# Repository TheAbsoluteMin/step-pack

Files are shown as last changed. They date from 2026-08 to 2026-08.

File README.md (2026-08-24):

# step-pack

















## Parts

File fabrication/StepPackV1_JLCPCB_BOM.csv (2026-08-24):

Designator | Value | Footprint | LCSC Part Number
C2 | 4.7uF_100V_BUCK | Capacitor_SMD:C_1206_3216Metric | C22367839
C3,C5 | 22uF_25V | Capacitor_SMD:C_0805_2012Metric | C45783
C4,C9,C11,C12,C21 | 0.1uF_50V | Capacitor_SMD:C_0603_1608Metric | C14663
C6,C13 | 1uF_50V | Capacitor_SMD:C_0603_1608Metric | C15849
D1 | WS2812B-2020 | LED_SMD:LED_WS2812B-2020_PLCC4_2.0x2.0mm | C5349955
D4 | D_Zener_SMCJ30A | Diode_SMD:D_SMC | C408374
D5 | D_Schottky_60V | Diode_SMD:D_SOD-123F | C116099
D6,D7 | PMEG3010BEA | Diode_SMD:D_SOD-323 | C53100376
J2 | USB_C_Receptacle_USB2.0_16P | Connector_USB:USB_C_Receptacle_HRO_TYPE-C-31-M-12 | C165948
J4 | I2C_CONN | Connector_JST:JST_SH_SM04B-SRSS-TB_1x04-1MP_P1.00mm_Horizontal | C51940130
L1 | Inductor_10uH_1.2A | Inductor_SMD:L_Bourns-SRN4018 | C5291802
R3,R4 | 5.1k_USB_CC | Resistor_SMD:R_0603_1608Metric | C23186
R5,R6 | 10k | Resistor_SMD:R_0603_1608Metric | C25804
R7,R8,R9 | 22ohms | Resistor_SMD:R_0603_1608Metric | C23345
R10 | 100k_BUCK | Resistor_SMD:R_0603_1608Metric | C25803
R12 | 1k_UART | Resistor_SMD:R_0603_1608Metric | C21190
R15,R16 | 4.7k | Resistor_SMD:R_0603_1608Metric | C23162
SW2,SW3 | SW_Push | Button_Switch_SMD:SW_SPST_B3U-1000P | C49234121
U1 | ESP32-S3-MINI-1 | RF_Module:ESP32-S2-MINI-1 | C2913206
U4 | USBLC6-2SC6 | Package_TO_SOT_SMD:SOT-23-6 | C2827654
U5 | AP2112K-3.3 | Package_TO_SOT_SMD:SOT-23-5 | C51118
U6 | LMR16006YQ5 | Package_TO_SOT_SMD:SOT-23-6 | C962072

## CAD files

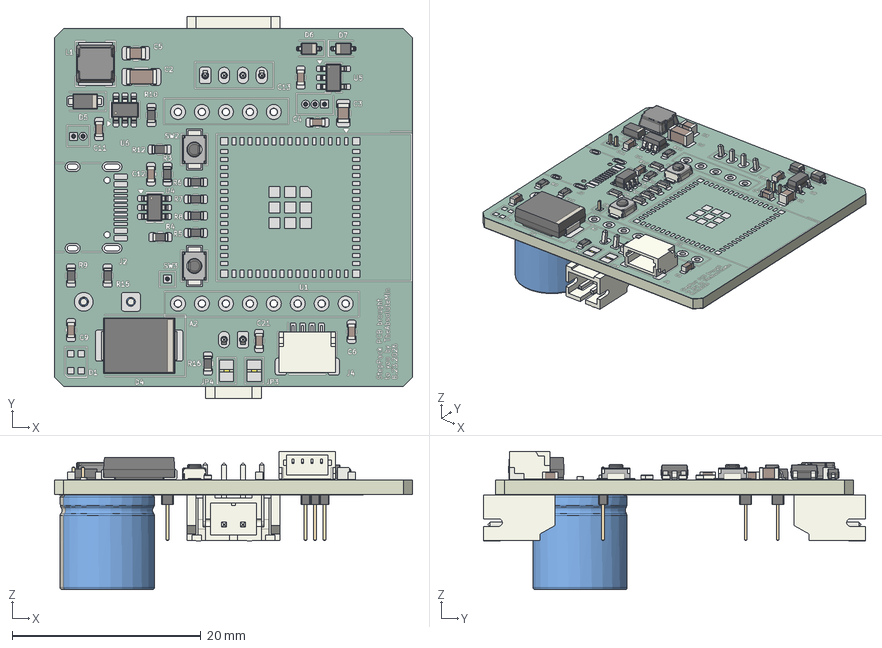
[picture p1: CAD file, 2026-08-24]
3D_Models/StepPack_PCB.step
38.0 x 40.5 x 14.6 mm
R_0603_1608Metric x 11
SOT-23-6 x 2
SW_SPST_B3U-1000P x 2
C_0603_1608Metric x 7
JST_SH_SM04B-SRSS-TB_1x04-1MP_P1.00mm_Horizontal
L_Bourns-SRN4018
D_SMC
SOT-23-5
C_0805_2012Metric x 2
C_1206_3216Metric
D_SOD_123F
D_SOD-323 x 2
PinHeader_1x01_P100mm_Vertical
JST_S4B_PH_K
CP_Radial_D100mm_P500mm
PinHeader_1x02_P100mm_Vertical
JST_S2B_PH_K
PinHeader_1x03_P100mm_Vertical
backpack_copper
backpack_pad
backpack_via
backpack_silkscreen x 2
backpack_soldermask x 2
backpack_PCB

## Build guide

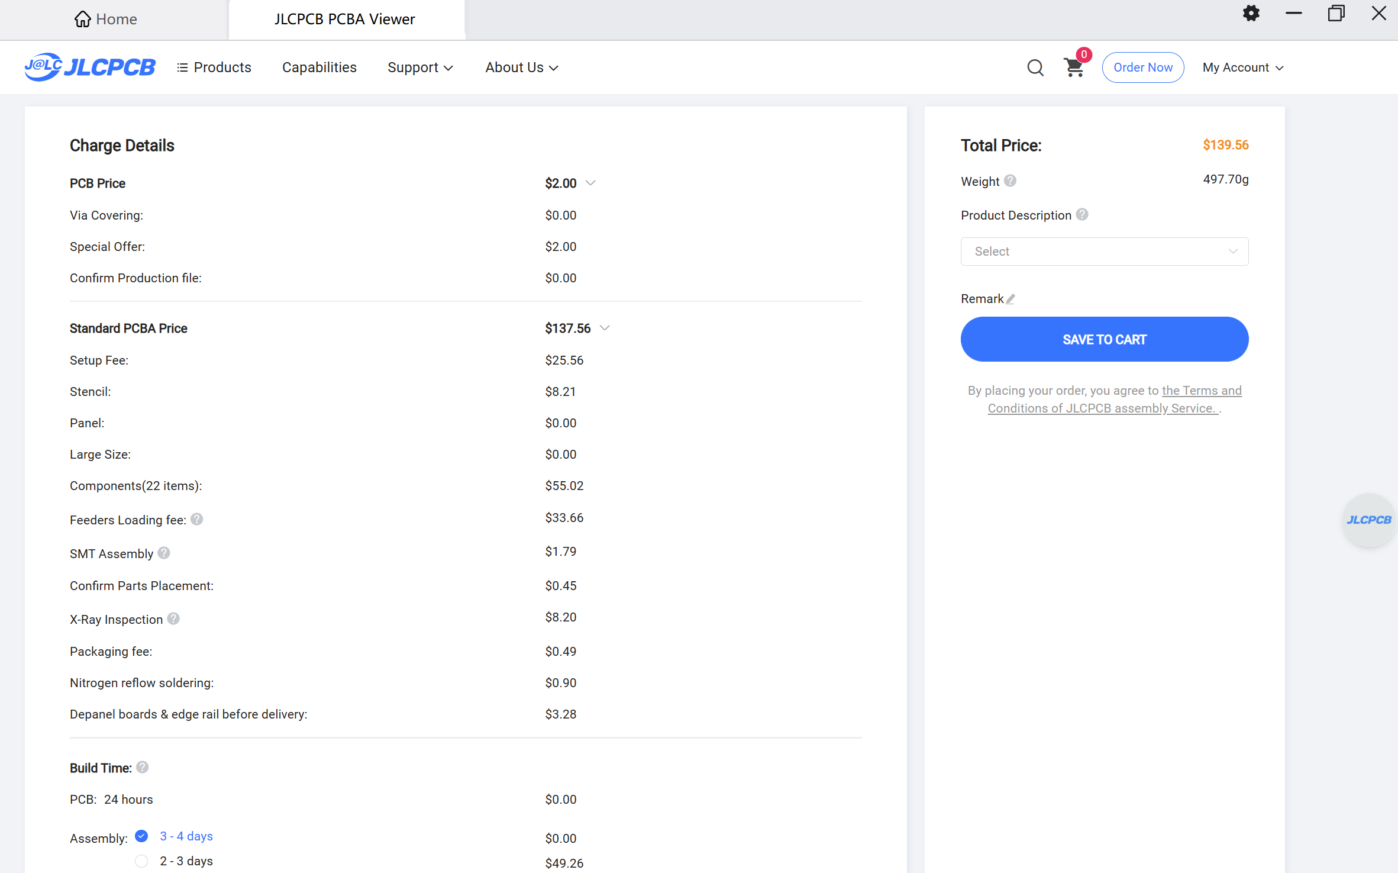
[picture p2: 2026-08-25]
fabrication/Screenshot 2026-08-24 203620.png

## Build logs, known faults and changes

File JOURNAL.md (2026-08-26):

---
title: "StepPack"
author: "TheAbsoluteMin"
description: "A smart, wireless enabling backpack for stepper motors."
created_at: "2026-08-12"
---

# Log 1: August 12, 2026 - Initial Schematics - 2.1 hours
Timelapse <a href="https://lapse.hackclub.com/timelapse/6FzYQxMGaGmf">link</a>.

I had recently worked with stepper motors for a conveyor belt I had built, and I was astonished at the incredible number of wires needed solely to run a single NEMA 17 stepper motor! Each stepper motor needs about 4 wires and many more for each driver! Using multiple can quickly become a mess, especially in robotics applications. Thus, I wondered if there was a way to reduce all that clutter, and as my eyes were looking at an ESP32 sitting on a shelf in front of me, I came up with an idea. 

With the fast, wireless data transfers of the ESP32's ESP-NOW technology, I could send movement signals to each connected stepper motor with their own driver PCB, drastically reducing the overall wire count between each stepper motor to only 2 wires. Even better, you could add more and more stepper motors, and still only use 2 wires, power and ground, to connect them all! I hope as this project progresses, I can create a comprehensive "backpack" with more essential features that can make using stepper motors easier and smarter!

As I began my research, I began compiling certain components for the PCB backpack, and I had to choose wisely as I had to fit everything in a small 42mm by 42mm back. I began with the ESP32-S3 MINI 1, and I hope to integrate the TMC2209 driver and the AS5600 magnetic encoder later for a true smart, closed looped design. 



Right now, my schematic is quite a mess as I am still optimizing my parts for my project.



However, with the help of the Espressif Systems datasheet, I was able to begin wiring the ESP32-S3 MINI 1!


**Total time spent: 2.1 hours**

---

# Log 2: August 13, 2026 - Power Design Schematics - 2.2 hours
Timelapse <a href="https://lapse.hackclub.com/timelapse/Z9I2UxFSzDmm">link</a>.

Today, I began working on the power management system. Starting with the USB-C receptacle, I wired it with the USBLC6-2SC6 ESD protection chip. Initially, I wanted to avoid doing so because of a past difficulty of maintaining equal lengths of data lines in a past project. However, I realized a way to avoid my past challenge as it turns out that pins 1 and 6 are practically identical to pins 3 and 4, meaning I could wire either D+ or D- into them! I had thought D+ was only supposed to go in pins 1 and 6 before, which complicated wiring!



When I got to the VBUS 5V line of the USB-C, I realized that I would need to somehow power the ESP32-S3 MINI 1 when I flash the code. The problem is that I initially planned to step down 24V to power the MCU during normal operation. This meant I had to include the AP2112K-3.3 to step down the voltage for the MCU. 



In order to safely handle both the USB-C 5V power and buck converter's stepped down power of 24V to 5V, I implemented the BAT54C in order to connect the two power sources, which would then be stepped down to a clean 3.3V. With this, I also can safely use one power source or even both at the same time!



Unlike the AP2112K-3.3, the LMR16006YQ5 buck regulator was much more complicated to wire.



**Total time spent: 2.2 hours**

---

# Log 3: August 14, 2026 - Schematics Continued - 1.6 hours
Timelapse <a href="https://lapse.hackclub.com/timelapse/vkxOGXVv4BmJ">link</a>.

After realizing that the ESP32-S3 MINI 1 could draw up to 500mA, I had to change the BAT54C as it could only handle up to 200mA. Thus, I chose the PMEG2010EA diodes, and I made my own diode OR gate in order to keep the same capability to handle both the USB-C and buck regulator power sources.



Then, I started wiring the TMC2209 stepper motor driver. Wow, it was quite some work to get all the parts wired, especially the capacitors. Fortunately, I was able to reference the official schematics of the SilentStepStick module.





**Total time spent: 1.6 hours**

---

# Log 4: August 15, 2026 - Tiny Edits Schematics - 0.3 hours
Timelapse <a href="https://lapse.hackclub.com/timelapse/_rkijpWBezsx">link</a>.

Today, I did not have much time to work on my project, so I made some tiny edits to the TMC2209 module. After recreating the schematic from the official reference, I had to adapt it.

Specifically, I had to make sure that the ESP32-S3 MINI 1 could safely interact with the stepper motor driver on 3.3V logic.




It was strange that the official schematics wired the bigger capacitors a bit isolated from the others on the VM line, so I changed it to be a little more intuitive.




**Total time spent: 0.3 hours**

---

# Log 5: August 16, 2026 - Schematics Completion - 3.1 hours
Timelapse <a href="https://lapse.hackclub.com/timelapse/vb9HLf_P8bR-">link</a>.

Today was a big day! I began by continuing to optimize the TMC2209 module. Since I chose the Bourns potentiometer, turning the potentiometer's screw counterclockwise would increase the reference voltage. 



However, since this is a custom board and not another stepper motor driver for a printer, I could make it more intuitive by readjusting the pins to allow clockwise motion to increase the reference voltage instead.




Then, as I was enabling UART between the MCU and stepper motor driver, I realized that I did not need that external potentiometer to control current! I could have it all done in software, so I deleted it and left VREF floating.



I also moved the LED down the power line after the diode OR gate, so that I could also have a physical status LED during normal operation instead of solely when I flash code via USB-C. 



In order to protect against back EMF generated by the stepper motor, I added a TVS diode and a 470uF capacitor.



For easy configuration when using multiple StepPack modules together with multiple stepper motors, I included a dip switch so that each stepper motor could be quickly assigned a hardware address that would be handled in the firmware.



To make my project versatile, I included an I2C port so that sensors could be added to the PCB.



Finally, I wired the AS5600 encoder.



With that, the schematics is finished for now!

**Total time spent: 3.1 hours**

---

# Log 6: August 17, 2026 - Starting PCB - 2.3 hours
Timelapse <a href="https://lapse.hackclub.com/timelapse/PgFwSBR3iHUW">link</a>.

After verifying and organizing my modules and parts into clean schematic sheets, I transitioned to the PCB editor.




I started by setting up my edge.cuts layout with the standard footprint of the back of a NEMA 17 stepper motor.



Placing huge parts like the ESP32-S3 MINI 1 module while considering the header pins for the AS5600 magnetic encoder breakout module proved extremely difficult as I could not find a clean way to fit them together without colliding. The reason I chose to use the breakout module for the magnetic encoder rather than integrating the bare chip on the back of the PCB was because the ESP32-S3 MINI 1's antenna must be far away from the back of the stepper motor. While I could keep it hanging over the stepper motor, it would ruin the flush look of the back square shape of the stepper motor. Instead, I will keep the magnetic encoder close to a magnet on the stepper motor's back shaft for accurate position tracking while the WiFi antenna on the main PCB will be far away in order to preserve its WiFi signal.



Since the header pins got in the way, I decided to move them so that I could connect to the magnetic encoder breakout board with flexible wires instead. Even with the space freed up, I found out that my other parts, like the JST connectors and dip switch were too big.



I hope I can find a way to optimize spacing on the small PCB!

**Total time spent: 2.3 hours**

---

# Log 7: August 18, 2026 - PCB Parts Placement - 3 hours
Timelapse <a href="https://lapse.hackclub.com/timelapse/B5Cuqg-HF0T3">link</a>.

Today, I continued trying to fit everything within the square space neatly while keeping the JST connectors at the center edges. While it gave a bit of a symmetrical look, everything was still too big!



In order to make sure the small parts would all fit as well, I began to design a corner for the power regulation and TMC2209 modules.



Frustrated at all the parts, I decided to transition to some routing, and I worked on the USB-C receptacle routing. However, that only tested my patience further as it was not simple given the orientation of the ESP32-S3 MINI 1 module!



After that, I returned to the TMC2209 module. Figuring out how to squeeze all its capacitors was a huge headache!



**Total time spent: 3 hours**

---

# Log 8: August 19, 2026 - TMC2209 Routing - 5 hours
Timelapse <a href="https://lapse.hackclub.com/timelapse/WGPjW4hOCeL9">link</a>.

I finally got the motivation and courage to route the bare TMC2209 module today! Let me warn you: it was not pretty.

Packing all the motor power input capacitors as outlined by the TMC2209 datasheet was extremely difficult. I had to figure out how to cleanly move the positive power line so that it would easily connect to the different pins on the TMC2209, and it took quite some time rotating the capacitors around and around until I got it.




Placing the VCP/VS and CPI/CPO capacitors proved difficult as they both had to be routed to the TMC2209 pins in under a short distance of about 5mm, but they were both next to each other! Even after so many attempts, I could barely get the VCP/VS capacitor routed in under 10mm as its required 24V connection was on an entire different edge, which greatly increased trace length!



I settled for my best attempt of about a 9mm total trace distance for the VCP/VS capacitor and 6mm total trace distance for the CPI/CPO capacitor, and I began to route the heavy 24V motor input line.



I ended up switching to a 4 layer board as I simply had no space to fit all the wiring as most of the traces needed to be big to handle the high voltage and current.



After routing most of the pins, I realized that I had overlooked a fatal detail: the vias. It turns out that standard vias can only handle around 1 Ampere, which is not enough for the high current draw of stepper motors... This means I had to go back and squeeze bigger vias into the tight spaces!!! I was able to do so for some of the high current vias, but I had to sacrifice some clearance.




**Total time spent: 5 hours**

---

# Log 9: August 20, 2026 - Starting PCB Redesign - 1.1 hours
Timelapse <a href="https://lapse.hackclub.com/timelapse/_uED5JcFK8KI">link</a>.

Considering my past attempt in routing the PCB, I decided to make a huge decision for my project. As the goal of the project was not to optimize for the best TMC2209 layout, I decided to replace the bare chip for the TMC2209 StepStick breakout module. The integration of existing technologies would not only streamline the PCB routing but also enable my project to reliably fulfill its key purpose of providing a cleaner and data wireless option for controlling numerous stepper motors.



As I began to adapt this change, I had to adapt the schematic symbol for the A4988 stepper motor driver so that it reflected the correct pin locations as the TMC2209 module.



Moving to the PCB editor again, I completely began the PCB anew with a new design in mind. I was looking at some closed loop stepper motor PCBs, and I was inspired by their symmetry.



I decided to make the USB-C routing easier by putting the ESP32-S3 MINI 1 on the opposite end, which also balanced out the board appearance.




**Total time spent: 1.1 hours**

---

# Log 10: August 21, 2026 - PCB Routing - 5.4 hours
Timelapse <a href="https://lapse.hackclub.com/timelapse/slqjmzkDkAr4">link</a>.

As I redesigned the placement of the rest of the parts, including the JST connectors, I realized I did not have room for my TMC2209 step stick module. However, I realized that I could solder one side of header pins of the step stick module to the main PCB while using wires to attach to the other side of header pins!



Routing the LMR16006YQ5 buck regulator, which would step down 24V to 5V, was a bit difficult because I had to try to keep everything close while keeping in mind assembly constraints of JLCPCB PCBA. For example, I had to use a copper pour to connect the multiple SW pin 6 components.



The USB-C receptacle was a little tricky, but I managed to fit all the routing in a tight space. I had to admit, with all the tiny parts on the PCB, it was getting a little too crowded!




As I was routing the LDO AP2112K-3.3 and LED, I realized that I ran out of space and that I could not place the LED in the antenna keep out zone of the ESP32-S3 MINI 1 module. Unfortunately, I would have to move it all the way across the board.




I also realized that my buttons for the ESP32 enable and boot pins were too big, so I switched to the tiny B3U-1000P footprint.



I tried placing it above the 24V input JST connector, but I do not think I will keep it there.

**Total time spent: 5.4 hours**

---

# Log 11: August 22, 2026 - PCB Completion - 5 hours
Timelapse <a href="https://lapse.hackclub.com/timelapse/PvYEJbqqGRbh">link</a>.

With some time, I finally found a place for my two switches! They actually naturally fit near the USB-C receptacle, which was great!



I also began routing the data and signal traces for the board, and I had to change the pin connections a couple of times in order to optimize trace lengths and locations.



The UART connection was somewhat difficult as I had to loop around a lot of wires.



Since I ran out of room for my 3.3V line, I had to route it around the edges of the board.




However, I did have to route underneath the ESP32, which made me uneasy as that could interrupt the ground plane on the back layer.

Since I placed the LED far away from the merged 5V power line after the diode OR gate, I had route the 5V line so far away and go around many obstacles!






With some copper fills, I made a dual layer ground copper fill!



**Total time spent: 5 hours**

---

# Log 12: August 23, 2026 - PCB Final Touches - 2 hours
Timelapse <a href="https://lapse.hackclub.com/timelapse/YbPYQX-tfSPW">link</a>.

Today, I started ordering my board on JLCPCB.



I also began matching my parts with parts on JLCPCB Assembly.



However, it was extremely difficult as it took quite some time to balance cost and quality.

I had to implement some edits on the PCB after realizing some errors that needed fixing! I needed to stitch up the ground plane that I had broken up before with vias.



Also, it appeared that as I was moving around the data connections on the ESP32, I had accidentally moved the SDA and SCL lines onto the strapping GPIO pins 45 and 46! I thus had to adjust the schematic and PCB to move them away from those pins.




After verifying my order on JLCPCB, I found it to be a shocking $139.56 to order 5 assembled boards!



I will have to optimize the cost or order less assembled boards later.

**Total time spent: 2 hours**

---

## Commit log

2026-08-23 Add Gerber Files
2026-08-23 Add PCB STEP file
    [StepPack_PCB.step]
2026-08-23 Move to 3D_models folder
    [StepPack_PCB.step]
2026-08-23 Add PCB STEP model
    [StepPack_PCB.step]
2026-08-23 Create PCB folder
2026-08-23 Add KiCad files
    [POWER.kicad_sch, backpack.kicad_pcb, backpack.kicad_sch]
2026-08-23 Update file name
    [step-pack.kicad_pcb]
2026-08-23 Add updated PCB files
    [backpack.kicad_pcb]
2026-08-23 Add updated Gerber files
2026-08-23 Rename file
    [step-pack.kicad_pcb]
2026-08-23 Add updated PCB STEP file
    [StepPack_PCB.step]
2026-08-23 Add fixed Gerber files
2026-08-23 Add fixed PCB STEP file
    [StepPack_PCB.step]
2026-08-23 Add fixed KiCad files
    [backpack.kicad_pcb]
2026-08-24 Add 8.23.2026 updated gerber files
2026-08-24 Add updated 8.23.2026 PCB STEP file
    [StepPack_PCB.step]
2026-08-24 Add fixed 8.23.2026 KiCad files
    [POWER.kicad_sch, backpack.kicad_pcb, backpack.kicad_sch]
2026-08-24 Add JLCPCB Assembly BOM
    [StepPackV1_JLCPCB_BOM.csv]
2026-08-24 Add JLCPCB CPL file
    [StepPack_JLCPCB_CPL.csv]
2026-08-24 Update JLCPCB assembly files
    [StepPackV1_JLCPCB_BOM.csv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]
